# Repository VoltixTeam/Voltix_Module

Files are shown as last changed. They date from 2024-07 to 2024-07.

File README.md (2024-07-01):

# Voltix Module Hardware Design Files



The Voltix Module is a stamp-sized unit (27.2mm by 15.2mm) that can be soldered onto a user's \ac{pcb} with additional circuitry like sensors or harvesters to create deployment-ready battery-free devices quickly.
It integrates harvesting circuitry, two MCUs, an RTC, a PCB antenna, and an LED on a compact 4-layer PCB enclosed in a metal RF shield.
The module features breadboard-compatible castellated holes exposing essential signals, including 11 GPIO, two of which can also function as analog inputs.
Four additional signals on the back of the module are available when reflow-soldered onto a carrier board.

For more details and pinouts, refer to the [documentation](https://voltix-docs.vercel.app/hardware/module.html).

Latest design files:
 - [Schematics](https://voltix-docs.vercel.app/artifacts/module/latest/schematics.pdf)
 - [Layout](https://voltix-docs.vercel.app/artifacts/module/latest/pcb.pdf)
 - [3D rendering](https://voltix-docs.vercel.app/artifacts/module/latest/3drendering.png)
 - [3D step model](./resources/VoltixModule.step)
 - [Kicad schematic symbol](./resources/VoltixModule.kicad_sym)
 - [Kicad footprint](./resources/VoltixModule.pretty)

Rendering of Voltix module Voltix module

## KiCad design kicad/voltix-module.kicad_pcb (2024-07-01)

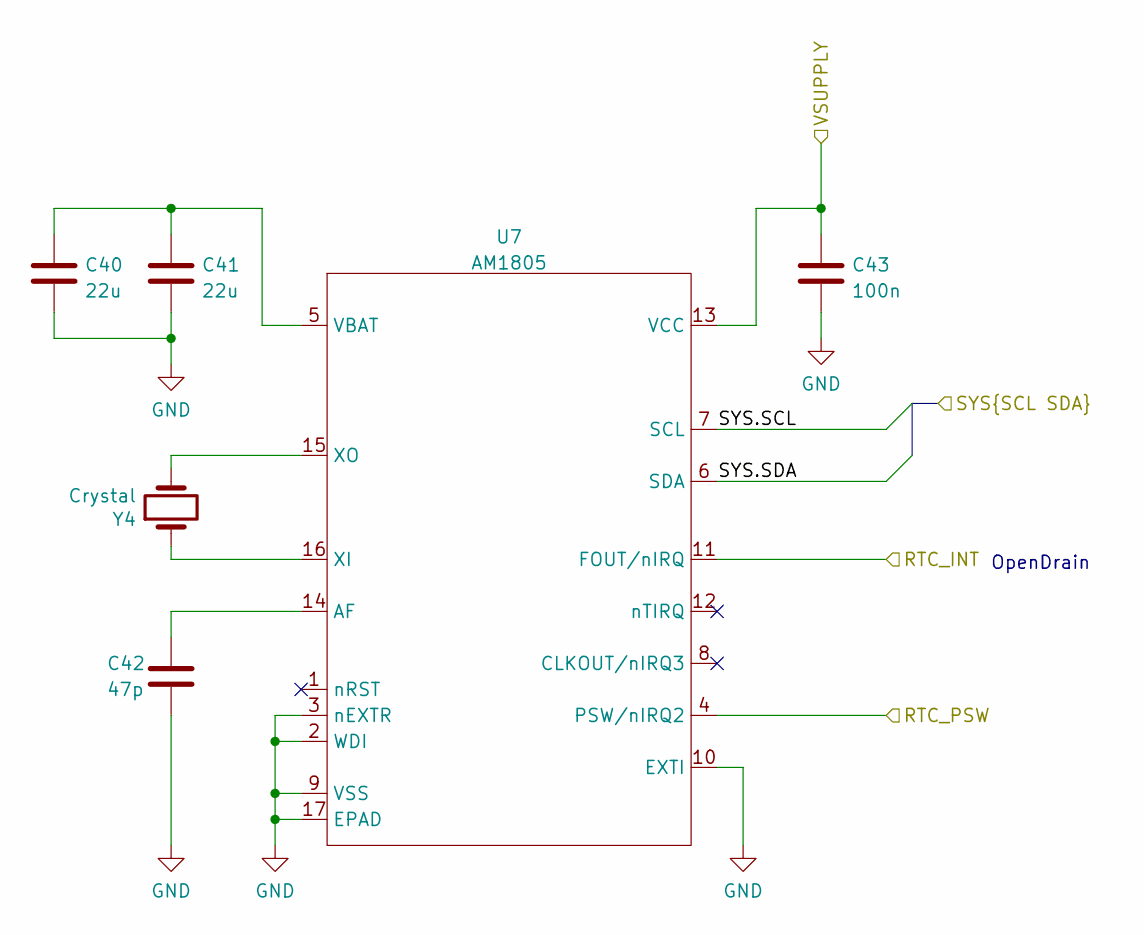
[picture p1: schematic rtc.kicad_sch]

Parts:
C40, C41: 22u; C_0402_1005Metric; MPN GRM158R61A226ME15D
C42: 47p; C_0201_0603Metric; MPN CC0201JRNPO9BN470
C43: 100n; C_0201_0603Metric; MPN GRM033R61A104ME15D
U7: AM1805; AM_QFN16; MPN AM1805
Y4: Crystal; ECX-12R; MPN CM8V-T1A-32.768KHZ-9PF-20PPM-TA-QC

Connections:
/Board Connectors/SYS.SCL: U7.7 (SCL); also elsewhere on the board
/Board Connectors/SYS.SDA: U7.6 (SDA); also elsewhere on the board
/Board Connectors/VSHUNT: C43.1, U7.13 (VCC); also elsewhere on the board
/MSP430FR/RTC_INT: U7.11 (FOUT/nIRQ); also elsewhere on the board
/Power Supply/RTC_PSW: U7.4 (PSW/nIRQ2); also elsewhere on the board
GND: C40.2, C41.2, C42.2, C43.2, U7.2 (WDI), U7.3 (nEXTR), U7.9 (VSS), U7.10 (EXTI), U7.17 (EPAD); also elsewhere on the board
unnamed: C42.1, U7.14 (AF)
unnamed: C40.1, C41.1, U7.5 (VBAT)
unnamed: U7.16 (XI), Y4.1
unnamed: U7.15 (XO), Y4.2

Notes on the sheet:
OpenDrain

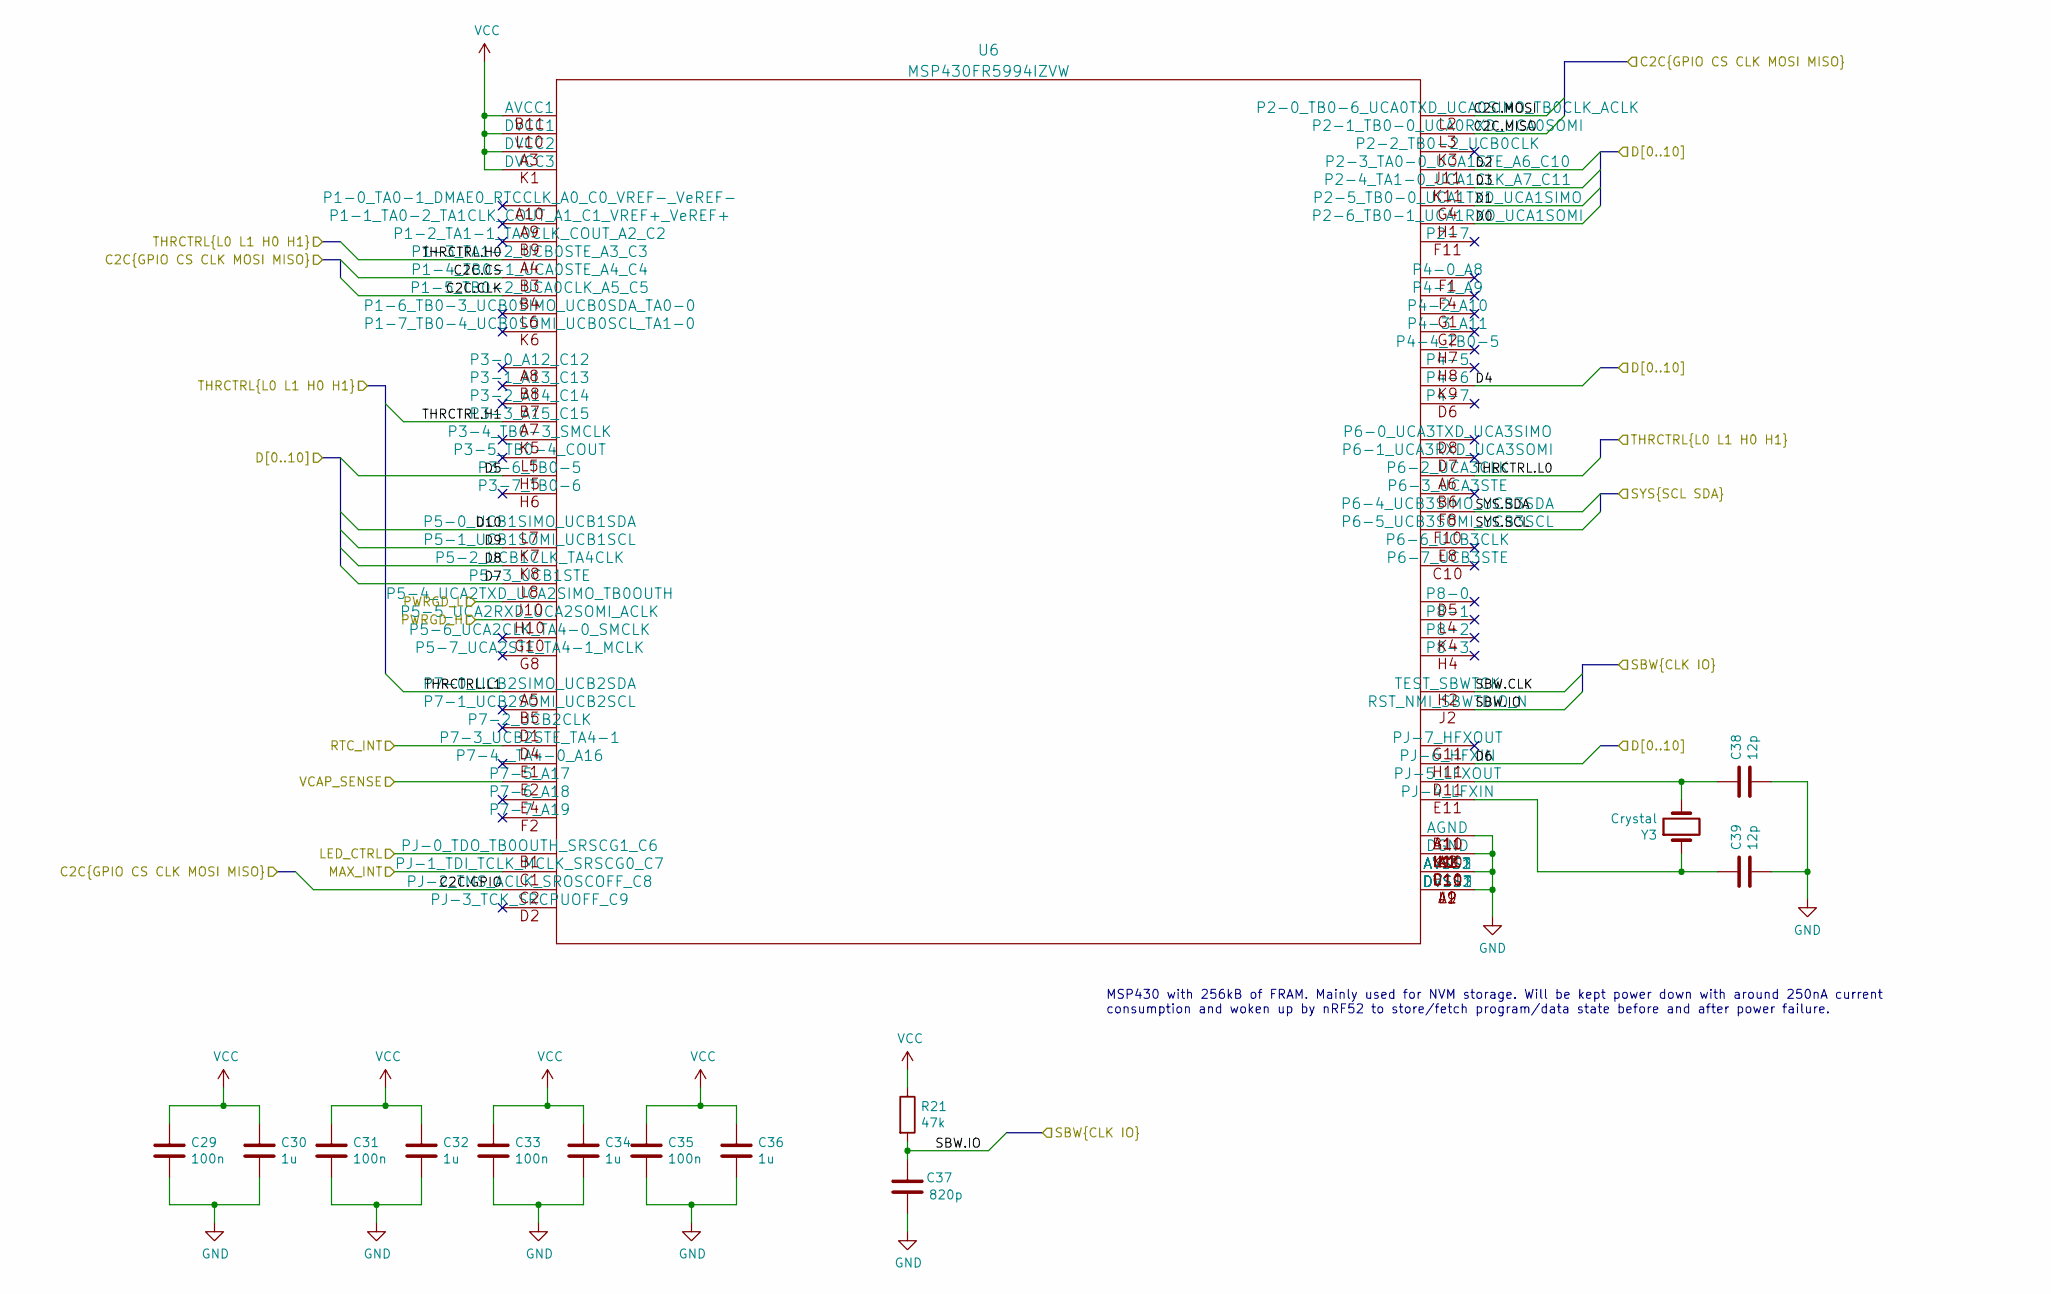
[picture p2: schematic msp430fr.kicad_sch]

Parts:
C29, C31, C33, C35: 100n; C_0201_0603Metric; MPN GRM033R61A104ME15D
C30, C32, C34, C36: 1u; C_0201_0603Metric; MPN GRM033R61C105ME15D
C37: 820p; C_0201_0603Metric; MPN GRM0335C1H821JE01D
C38, C39: 12p; C_0201_0603Metric; MPN GRM0335C1H120GA01D
R21: 47k; R_0201_0603Metric; MPN RC0201FR-0747KL
U6: MSP430FR5994IZVW; TI_ZVW; MPN MSP430FR5994IZVW
Y3: Crystal; ECX-12R; MPN CM8V-T1A-32.768KHZ-9PF-20PPM-TA-QC

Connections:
/Board Connectors/D0: U6.H1 (P2-6_TB0-1_UCA1RXD_UCA1SOMI); also elsewhere on the board
/Board Connectors/D1: U6.G4 (P2-5_TB0-0_UCA1TXD_UCA1SIMO); also elsewhere on the board
/Board Connectors/D2: U6.J11 (P2-3_TA0-0_UCA1STE_A6_C10); also elsewhere on the board
/Board Connectors/D3: U6.K11 (P2-4_TA1-0_UCA1CLK_A7_C11); also elsewhere on the board
/Board Connectors/D4: U6.K9 (P4-6); also elsewhere on the board
/Board Connectors/D5: U6.H5 (P3-6_TB0-5); also elsewhere on the board
/Board Connectors/D6: U6.H11 (PJ-6_HFXIN); also elsewhere on the board
/Board Connectors/D7: U6.L8 (P5-3_UCB1STE); also elsewhere on the board
/Board Connectors/D8: U6.K8 (P5-2_UCB1CLK_TA4CLK); also elsewhere on the board
/Board Connectors/D9: U6.K7 (P5-1_UCB1SOMI_UCB1SCL); also elsewhere on the board
/Board Connectors/D10: U6.L7 (P5-0_UCB1SIMO_UCB1SDA); also elsewhere on the board
/Board Connectors/LED_CTRL: U6.B1 (PJ-0_TDO_TB0OUTH_SRSCG1_C6); also elsewhere on the board
/Board Connectors/SBW.CLK: U6.H2 (TEST_SBWTCK); also elsewhere on the board
/Board Connectors/SBW.IO: C37.1, R21.2, U6.J2 (RST_NMI_SBWTDIO_N); also elsewhere on the board
/Board Connectors/SYS.SCL: U6.F10 (P6-5_UCB3SOMI_UCB3SCL); also elsewhere on the board
/Board Connectors/SYS.SDA: U6.F8 (P6-4_UCB3SIMO_UCB3SDA); also elsewhere on the board
/Board Connectors/VCAP_SENSE: U6.E2 (P7-5_A17); also elsewhere on the board
/Energy Management/PWRGD_H: U6.H10 (P5-5_UCA2RXD_UCA2SOMI_ACLK); also elsewhere on the board
/Energy Management/PWRGD_L: U6.J10 (P5-4_UCA2TXD_UCA2SIMO_TB0OUTH); also elsewhere on the board
/Energy Management/THRCTRL.H0: U6.A4 (P1-3_TA1-2_UCB0STE_A3_C3); also elsewhere on the board
/Energy Management/THRCTRL.H1: U6.A7 (P3-3_A15_C15); also elsewhere on the board
/Energy Management/THRCTRL.L0: U6.A6 (P6-2_UCA3CLK); also elsewhere on the board
/Energy Management/THRCTRL.L1: U6.A5 (P7-0_UCB2SIMO_UCB2SDA); also elsewhere on the board
/MSP430FR/C2C.CLK: U6.B4 (P1-5_TB0-2_UCA0CLK_A5_C5); also elsewhere on the board
/MSP430FR/C2C.CS: U6.B3 (P1-4_TB0-1_UCA0STE_A4_C4); also elsewhere on the board
/MSP430FR/C2C.GPIO: U6.C2 (PJ-2_TMS_ACLK_SROSCOFF_C8); also elsewhere on the board
/MSP430FR/C2C.MISO: U6.L3 (P2-1_TB0-0_UCA0RXD_UCA0SOMI); also elsewhere on the board
/MSP430FR/C2C.MOSI: U6.L2 (P2-0_TB0-6_UCA0TXD_UCA0SIMO_TB0CLK_ACLK); also elsewhere on the board
/MSP430FR/MAX_INT: U6.C1 (PJ-1_TDI_TCLK_MCLK_SRSCG0_C7); also elsewhere on the board
/MSP430FR/RTC_INT: U6.D4 (P7-3_UCB2STE_TA4-1); also elsewhere on the board
GND: C29.2, C30.2, C31.2, C32.2, C33.2, C34.2, C35.2, C36.2, C37.2, C38.2, C39.2, U6.A1 (DGND), U6.A2 (DVSS2), U6.A11 (AGND), U6.B10 (AGND), U6.C11 (AVSS1), U6.D10 (AVSS2), U6.E10 (AVSS3), U6.J1 (DVSS3), U6.K2 (DGND), U6.K10 (DGND), U6.L1 (DGND), U6.L9 (DVSS1), U6.L11 (DGND); also elsewhere on the board
unnamed: C39.1, U6.E11 (PJ-4_LFXIN), Y3.1
unnamed: C38.1, U6.D11 (PJ-5_LFXOUT), Y3.2
VCC: C29.1, C30.1, C31.1, C32.1, C33.1, C34.1, C35.1, C36.1, R21.1, U6.A3 (DVCC2), U6.B11 (AVCC1), U6.K1 (DVCC3), U6.L10 (DVCC1); also elsewhere on the board

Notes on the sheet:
MSP430 with 256kB of FRAM. Mainly used for NVM storage. Will be kept power down with around 250nA current consumption and woken up by nRF52 to store/fetch program/data state before and after power failure.

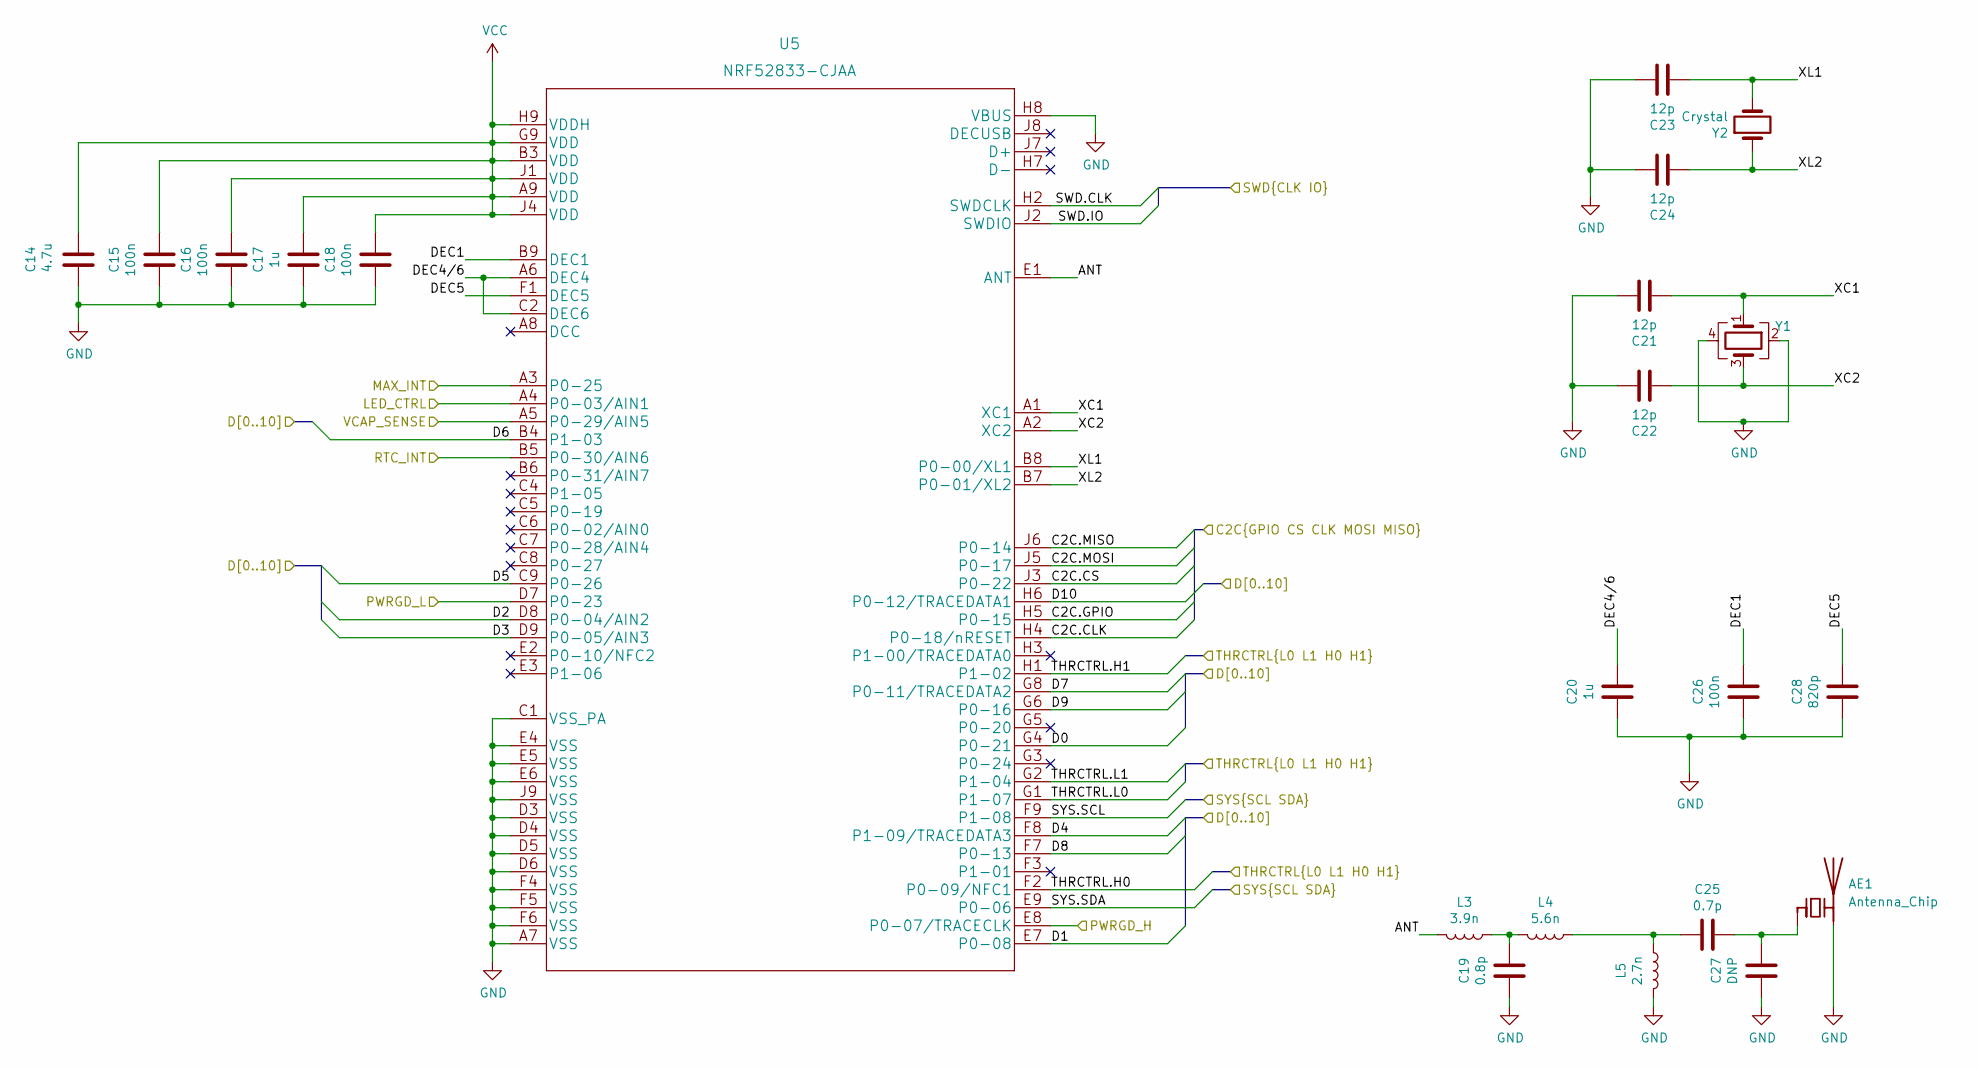
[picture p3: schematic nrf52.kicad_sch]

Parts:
AE1: Antenna_Chip; Texas_SWRA117D_2.4GHz_Left
C14: 4.7u; C_0402_1005Metric; MPN CL05A475MP5NRNC
C15, C16, C18, C26: 100n; C_0201_0603Metric; MPN GRM033R61A104ME15D
C17, C20: 1u; C_0201_0603Metric; MPN GRM033R61C105ME15D
C19: 0.8p; RFSMD_0201_0603Metric; MPN GRT0335C1HR80WA02D
C21, C22, C23, C24: 12p; C_0201_0603Metric; MPN GRM0335C1H120GA01D
C25: 0.7p; RFSMD_0201_0603Metric; MPN GRM0335C1HR70WA01D
C27: DNP; RFSMD_0201_0603Metric
C28: 820p; C_0201_0603Metric; MPN GRM0335C1H821JE01D
L3: 3.9n; RFSMD_0201_0603Metric; MPN LQP03TN3N9B02D
L4: 5.6n; RFSMD_0201_0603Metric; MPN LQP03TN5N6J02D
L5: 2.7n; RFSMD_0201_0603Metric; MPN LQP03TN2N7B02D
U5: NRF52833-CJAA; MPN NRF52833-CJAA
Y1: ECS-320-8-47B-7KM-TR; ECS_ECX-1247B; MPN ECS-320-CDX-2152
Y2: Crystal; ECX-12R; MPN CM8V-T1A-32.768KHZ-9PF-20PPM-TA-QC

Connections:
/Board Connectors/D0: U5.G4 (P0-21); also elsewhere on the board
/Board Connectors/D1: U5.E7 (P0-08); also elsewhere on the board
/Board Connectors/D2: U5.D8 (P0-04/AIN2); also elsewhere on the board
/Board Connectors/D3: U5.D9 (P0-05/AIN3); also elsewhere on the board
/Board Connectors/D4: U5.F8 (P1-09/TRACEDATA3); also elsewhere on the board
/Board Connectors/D5: U5.C9 (P0-26); also elsewhere on the board
/Board Connectors/D6: U5.B4 (P1-03); also elsewhere on the board
/Board Connectors/D7: U5.G8 (P0-11/TRACEDATA2); also elsewhere on the board
/Board Connectors/D8: U5.F7 (P0-13); also elsewhere on the board
/Board Connectors/D9: U5.G6 (P0-16); also elsewhere on the board
/Board Connectors/D10: U5.H6 (P0-12/TRACEDATA1); also elsewhere on the board
/Board Connectors/LED_CTRL: U5.A4 (P0-03/AIN1); also elsewhere on the board
/Board Connectors/SWD.CLK: U5.H2 (SWDCLK); also elsewhere on the board
/Board Connectors/SWD.IO: U5.J2 (SWDIO); also elsewhere on the board
/Board Connectors/SYS.SCL: U5.F9 (P1-08); also elsewhere on the board
/Board Connectors/SYS.SDA: U5.E9 (P0-06); also elsewhere on the board
/Board Connectors/VCAP_SENSE: U5.A5 (P0-29/AIN5); also elsewhere on the board
/Energy Management/PWRGD_H: U5.E8 (P0-07/TRACECLK); also elsewhere on the board
/Energy Management/PWRGD_L: U5.D7 (P0-23); also elsewhere on the board
/Energy Management/THRCTRL.H0: U5.F2 (P0-09/NFC1); also elsewhere on the board
/Energy Management/THRCTRL.H1: U5.H1 (P1-02); also elsewhere on the board
/Energy Management/THRCTRL.L0: U5.G1 (P1-07); also elsewhere on the board
/Energy Management/THRCTRL.L1: U5.G2 (P1-04); also elsewhere on the board
/MSP430FR/C2C.CLK: U5.H4 (P0-18/nRESET); also elsewhere on the board
/MSP430FR/C2C.CS: U5.J3 (P0-22); also elsewhere on the board
/MSP430FR/C2C.GPIO: U5.H5 (P0-15); also elsewhere on the board
/MSP430FR/C2C.MISO: U5.J6 (P0-14); also elsewhere on the board
/MSP430FR/C2C.MOSI: U5.J5 (P0-17); also elsewhere on the board
/MSP430FR/MAX_INT: U5.A3 (P0-25); also elsewhere on the board
/MSP430FR/RTC_INT: U5.B5 (P0-30/AIN6); also elsewhere on the board
/nRF52/ANT: L3.2, U5.E1 (ANT)
/nRF52/DEC1: C26.2, U5.B9 (DEC1)
/nRF52/DEC4/6: C20.2, U5.A6 (DEC4), U5.C2 (DEC6)
/nRF52/DEC5: C28.2, U5.F1 (DEC5)
/nRF52/XC1: C21.1, U5.A1 (XC1), Y1.1
/nRF52/XC2: C22.1, U5.A2 (XC2), Y1.3
/nRF52/XL1: C23.1, U5.B8 (P0-00/XL1), Y2.2
/nRF52/XL2: C24.1, U5.B7 (P0-01/XL2), Y2.1
GND: AE1.2 (PCB_Trace), C14.2, C15.1, C16.1, C17.1, C18.1, C19.1, C20.1, C21.2, C22.2, C23.2, C24.2, C26.1, C27.1, C28.1, L5.2, U5.A7 (VSS), U5.C1 (VSS_PA), U5.D3 (VSS), U5.D4 (VSS), U5.D5 (VSS), U5.D6 (VSS), U5.E4 (VSS), U5.E5 (VSS), U5.E6 (VSS), U5.F4 (VSS), U5.F5 (VSS), U5.F6 (VSS), U5.H8 (VBUS), U5.J9 (VSS), Y1.2, Y1.4; also elsewhere on the board
unnamed: AE1.1 (FEED), C25.2, C27.2
unnamed: C19.2, L3.1, L4.2
unnamed: C25.1, L4.1, L5.1
VCC: C14.1, C15.2, C16.2, C17.2, C18.2, U5.A9 (VDD), U5.B3 (VDD), U5.G9 (VDD), U5.H9 (VDDH), U5.J1 (VDD), U5.J4 (VDD); also elsewhere on the board

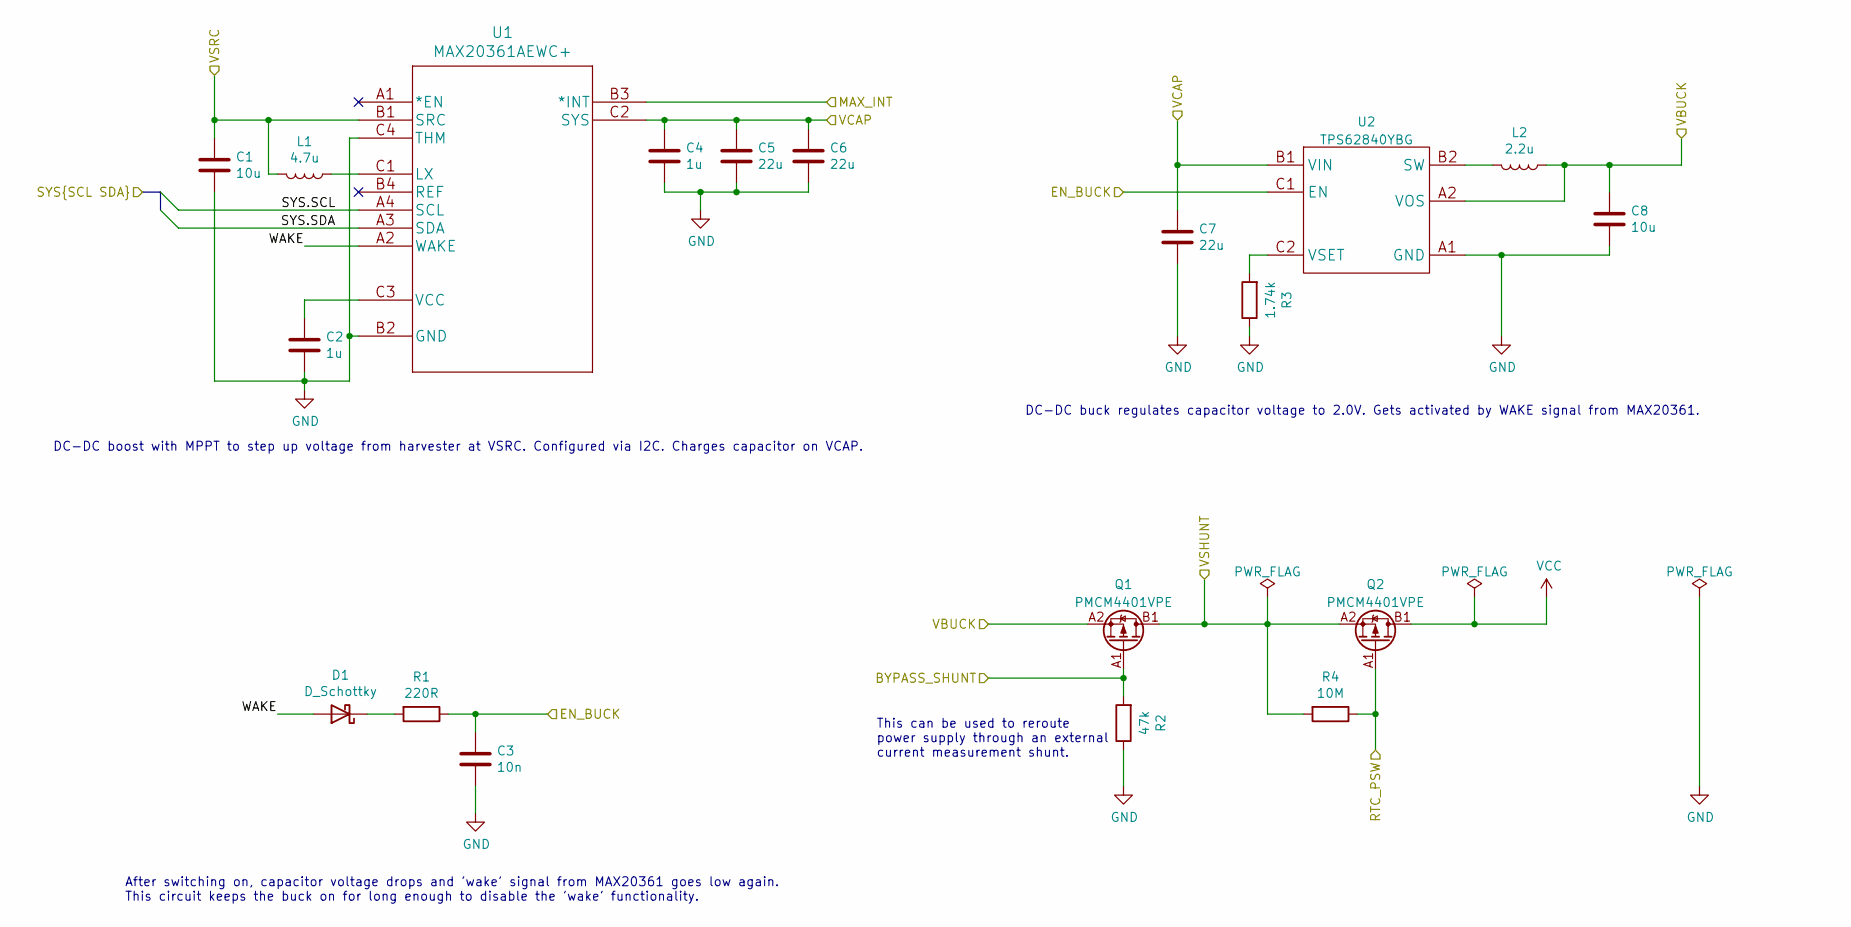
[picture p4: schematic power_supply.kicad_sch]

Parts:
C1, C8: 10u; C_0402_1005Metric; MPN GRM155R61A106ME11D
C2, C4: 1u; C_0201_0603Metric; MPN GRM033R61C105ME15D
C3: 10n; C_0201_0603Metric; MPN GRM033R61A103KA01D
C5, C6, C7: 22u; C_0402_1005Metric; MPN GRM158R61A226ME15D
D1: D_Schottky; D_0402_1005Metric; MPN CDBQR0130R
L1: 4.7u; L_0805_2012Metric; MPN MLZ2012N4R7LTD25
L2: 2.2u; L_0603_1608Metric; MPN MLZ1608N2R2LT000
Q1, Q2: PMCM4401VPE; NXP_WLCSP4; MPN PMCM4401VPEZ
R1: 220R; R_0201_0603Metric; MPN RC0201FR-07220RL
R2: 47k; R_0201_0603Metric; MPN RC0201FR-0747KL
R3: 1.74k; R_0201_0603Metric; MPN RC0201FR-071K74L
R4: 10M; R_0201_0603Metric; MPN RC0201FR-0710ML
U1: MAX20361AEWC+; MX_W121C1+2; MPN MAX20361AEWC+
U2: TPS62840YBG; TI_YBG6; MPN TPS62840YBG

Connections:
/Board Connectors/BYPASS_SHUNT: Q1.A1 (G), R2.2; also elsewhere on the board
/Board Connectors/EN_BUCK: C3.1, R1.1, U2.C1 (EN); also elsewhere on the board
/Board Connectors/SYS.SCL: U1.A4 (SCL); also elsewhere on the board
/Board Connectors/SYS.SDA: U1.A3 (SDA); also elsewhere on the board
/Board Connectors/VBUCK: C8.1, L2.1, Q1.A2 (S), U2.A2 (VOS); also elsewhere on the board
/Board Connectors/VCAP: C4.1, C5.1, C6.1, C7.1, U1.C2 (SYS), U2.B1 (VIN); also elsewhere on the board
/Board Connectors/VSHUNT: Q1.B1 (D), Q2.A2 (S), R4.2; also elsewhere on the board
/Board Connectors/VSRC: C1.1, L1.2, U1.B1 (SRC); also elsewhere on the board
/MSP430FR/MAX_INT: U1.B3 (*INT); also elsewhere on the board
/Power Supply/RTC_PSW: Q2.A1 (G), R4.1; also elsewhere on the board
/Power Supply/WAKE: D1.2 (A), U1.A2 (WAKE)
GND: C1.2, C2.2, C3.2, C4.2, C5.2, C6.2, C7.2, C8.2, R2.1, R3.1, U1.B2 (GND), U1.C4 (THM), U2.A1 (GND); also elsewhere on the board
unnamed: D1.1 (K), R1.2
unnamed: L1.1, U1.C1 (LX)
unnamed: C2.1, U1.C3 (VCC)
unnamed: L2.2, U2.B2 (SW)
unnamed: R3.2, U2.C2 (VSET)
VCC: Q2.B1 (D); also elsewhere on the board

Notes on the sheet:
After switching on, capacitor voltage drops and 'wake' signal from MAX20361 goes low again. This circuit keeps the buck on for long enough to disable the 'wake' functionality.
This can be used to reroute power supply through an external current measurement shunt.
DC-DC boost with MPPT to step up voltage from harvester at VSRC. Configured via I2C. Charges capacitor on VCAP.
DC-DC buck regulates capacitor voltage to 2.0V. Gets activated by WAKE signal from MAX20361.

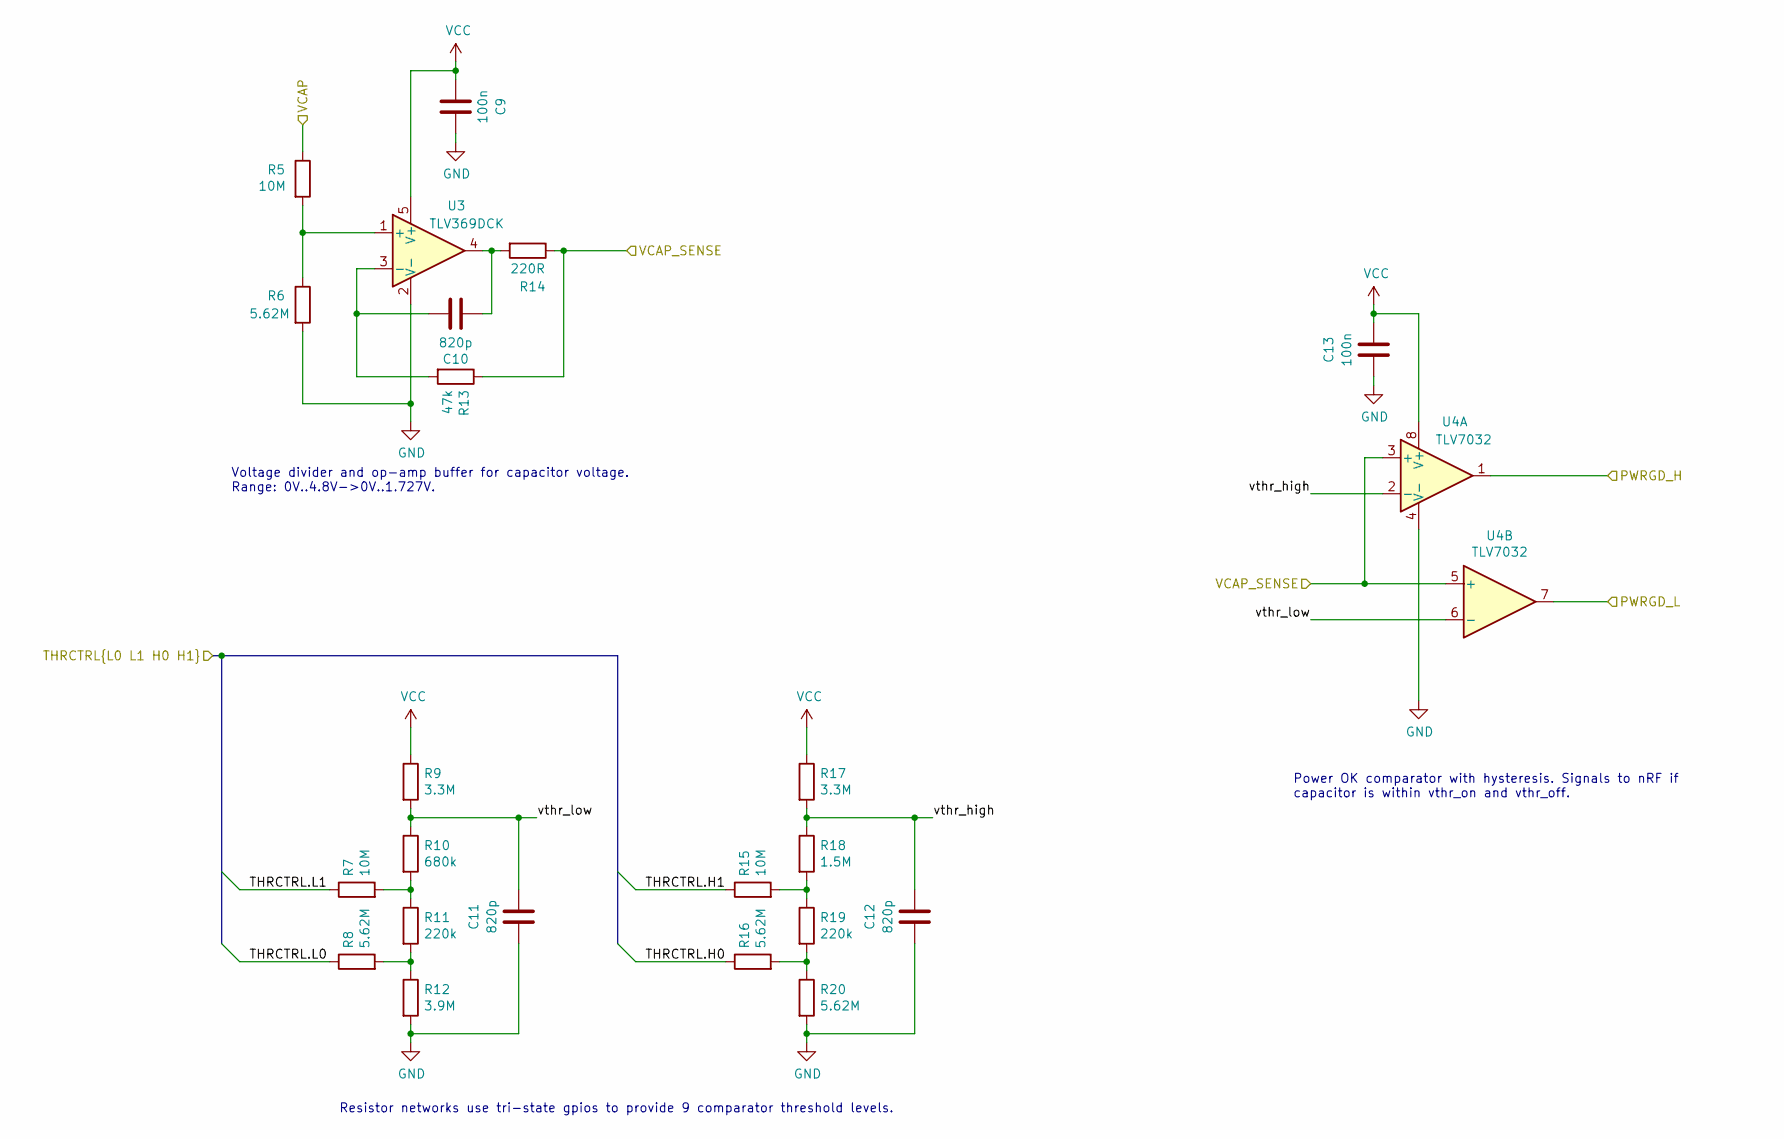
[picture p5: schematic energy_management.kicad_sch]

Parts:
C9, C13: 100n; C_0201_0603Metric; MPN GRM033R61A104ME15D
C10, C11, C12: 820p; C_0201_0603Metric; MPN GRM0335C1H821JE01D
R5, R7, R15: 10M; R_0201_0603Metric; MPN RC0201FR-0710ML
R6, R8, R16, R20: 5.62M; R_0201_0603Metric; MPN RC0201FR-075M62L
R9, R17: 3.3M; R_0201_0603Metric; MPN RC0201FR-073M3L
R10: 680k; R_0201_0603Metric; MPN RC0201FR-07680KL
R11, R19: 220k; R_0201_0603Metric; MPN RC0201FR-07220KL
R12: 3.9M; R_0201_0603Metric; MPN RC0201FR-073M9L
R13: 47k; R_0201_0603Metric; MPN RC0201FR-0747KL
R14: 220R; R_0201_0603Metric; MPN RC0201FR-07220RL
R18: 1.5M; R_0201_0603Metric; MPN RC0201FR-071M5L
U3: TLV369DCK; TI_SC70-5_DCK5; MPN TLV369IDCK
U4: TLV7032; TI_WSON8_DSG; MPN TLV7032DSG

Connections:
/Board Connectors/VCAP: R5.1; also elsewhere on the board
/Board Connectors/VCAP_SENSE: R13.1, R14.1, U4.3 (+), U4.5 (+); also elsewhere on the board
/Energy Management/PWRGD_H: U4.1; also elsewhere on the board
/Energy Management/PWRGD_L: U4.7; also elsewhere on the board
/Energy Management/THRCTRL.H0: R16.1; also elsewhere on the board
/Energy Management/THRCTRL.H1: R15.1; also elsewhere on the board
/Energy Management/THRCTRL.L0: R8.1; also elsewhere on the board
/Energy Management/THRCTRL.L1: R7.1; also elsewhere on the board
/Energy Management/vthr_high: C12.2, R17.2, R18.1, U4.2 (-)
/Energy Management/vthr_low: C11.2, R9.2, R10.1, U4.6 (-)
GND: C9.1, C11.1, C12.1, C13.1, R6.2, R12.2, R20.2, U3.2 (V-), U4.4 (V-), U4.9 (THM); also elsewhere on the board
unnamed: C10.1, R14.2, U3.4
unnamed: R7.2, R10.2, R11.1
unnamed: R8.2, R11.2, R12.1
unnamed: R15.2, R18.2, R19.1
unnamed: R16.2, R19.2, R20.1
unnamed: R5.2, R6.1, U3.1 (+)
unnamed: C10.2, R13.2, U3.3 (-)
VCC: C9.2, C13.2, R9.1, R17.1, U3.5 (V+), U4.8 (V+); also elsewhere on the board

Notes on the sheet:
Power OK comparator with hysteresis. Signals to nRF if capacitor is within vthr_on and vthr_off.
Resistor networks use tri-state gpios to provide 9 comparator threshold levels.
Voltage divider and op-amp buffer for capacitor voltage. Range: 0V..4.8V->0V..1.727V.

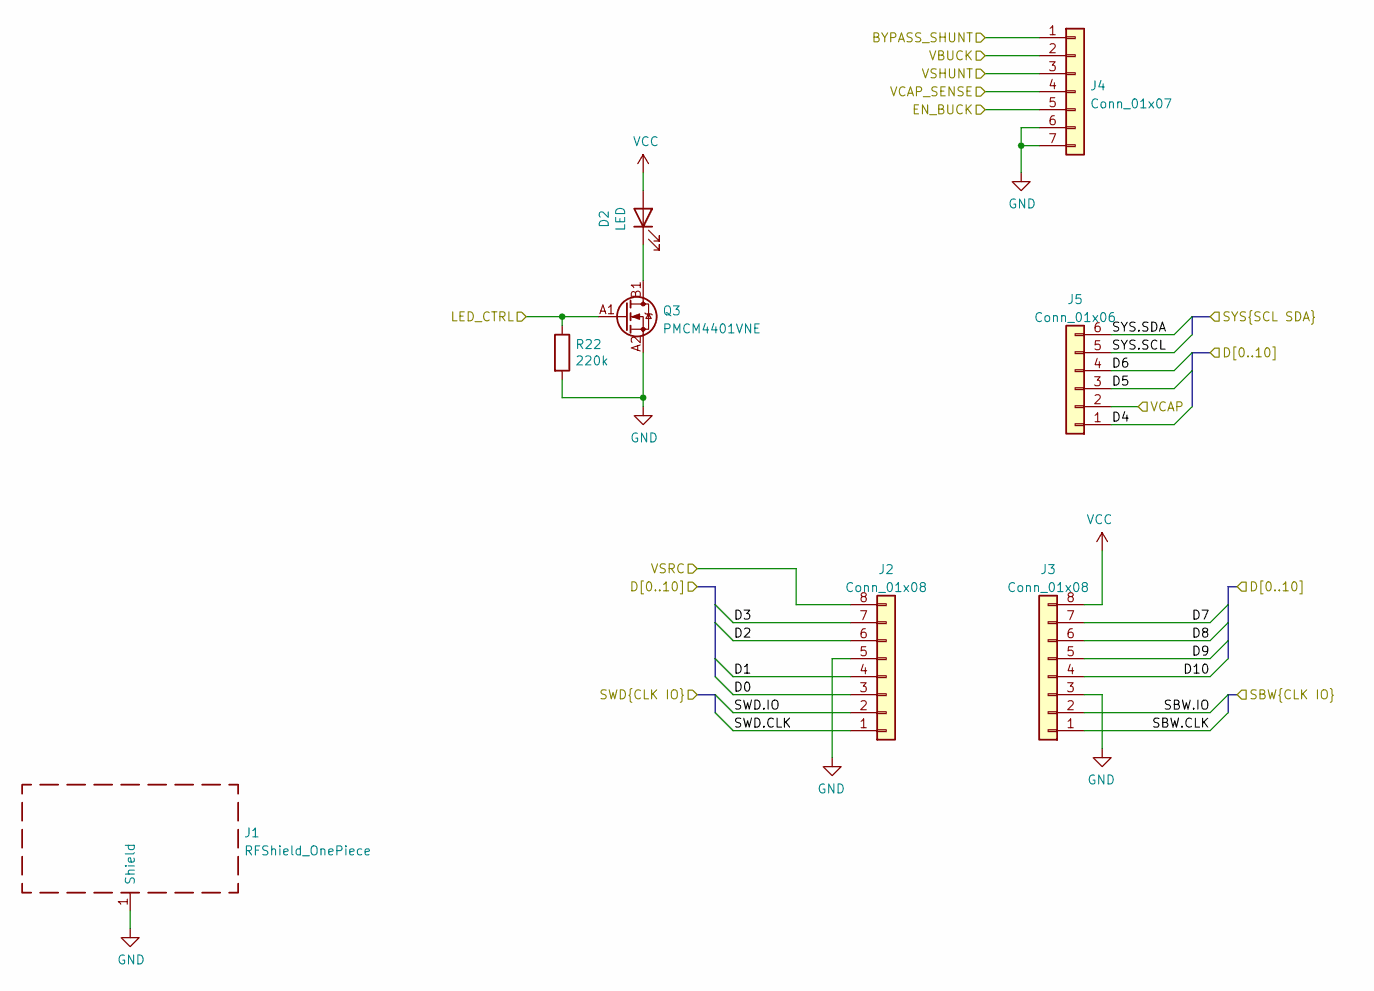
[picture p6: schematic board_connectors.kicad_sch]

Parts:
D2: LED; LED_0402_1005Metric; MPN 5988A20107F
J1: RFShield_OnePiece; EMI_SHIELD_CSTM
J2: Conn_01x08; CastellatedHoles_1x08_P2.54mm_Left
J3: Conn_01x08; CastellatedHoles_1x08_P2.54mm_Right
J4: Conn_01x07; BackPads
J5: Conn_01x06; CastellatedHoles_1x06_P2.54mm
Q3: PMCM4401VNE; NXP_WLCSP4; MPN PMCM4401VNEAZ
R22: 220k; R_0201_0603Metric; MPN RC0201FR-07220KL

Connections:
/Board Connectors/BYPASS_SHUNT: J4.1; also elsewhere on the board
/Board Connectors/D0: J2.3; also elsewhere on the board
/Board Connectors/D1: J2.4; also elsewhere on the board
/Board Connectors/D2: J2.6; also elsewhere on the board
/Board Connectors/D3: J2.7; also elsewhere on the board
/Board Connectors/D4: J5.1; also elsewhere on the board
/Board Connectors/D5: J5.3; also elsewhere on the board
/Board Connectors/D6: J5.4; also elsewhere on the board
/Board Connectors/D7: J3.7; also elsewhere on the board
/Board Connectors/D8: J3.6; also elsewhere on the board
/Board Connectors/D9: J3.5; also elsewhere on the board
/Board Connectors/D10: J3.4; also elsewhere on the board
/Board Connectors/EN_BUCK: J4.5; also elsewhere on the board
/Board Connectors/LED_CTRL: Q3.A1 (G), R22.1; also elsewhere on the board
/Board Connectors/SBW.CLK: J3.1; also elsewhere on the board
/Board Connectors/SBW.IO: J3.2; also elsewhere on the board
/Board Connectors/SWD.CLK: J2.1; also elsewhere on the board
/Board Connectors/SWD.IO: J2.2; also elsewhere on the board
/Board Connectors/SYS.SCL: J5.5; also elsewhere on the board
/Board Connectors/SYS.SDA: J5.6; also elsewhere on the board
/Board Connectors/VBUCK: J4.2; also elsewhere on the board
/Board Connectors/VCAP: J5.2; also elsewhere on the board
/Board Connectors/VCAP_SENSE: J4.4; also elsewhere on the board
/Board Connectors/VSHUNT: J4.3; also elsewhere on the board
/Board Connectors/VSRC: J2.8; also elsewhere on the board
GND: J1.1 (Shield), J2.5, J3.3, J4.6, J4.7, Q3.A2 (S), R22.2; also elsewhere on the board
unnamed: D2.1 (K), Q3.B1 (D)
VCC: D2.2 (A), J3.8; also elsewhere on the board

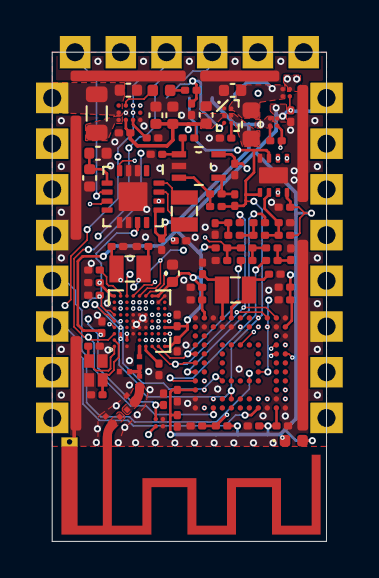
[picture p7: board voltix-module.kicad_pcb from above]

Board: 4 copper layers, 15.2 x 27.2 mm, 92 parts (1 on the bottom side), 74 nets.

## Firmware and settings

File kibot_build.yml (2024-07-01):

kibot:
  version: 1

preflight:
  check_zone_fills: true
  erc:
    filters:
    - filter: 'ignore simulation errors'
      error: 'simulation_model_issue'
  drc:
    filters:
    - filter: 'ignore pcb antenna issues'
      error: 'clearance'
      regex: '\(66\.752 mm, 98\.509672 mm\): Track \[Net-\(AE1-FEED\)\] on F\.Cu'
    - filter: 'ignore pcb antenna issues'
      error: 'clearance'
      regex: '\(67\.752 mm, 98\.5097 mm\): Track \(arc\) \[Net-\(AE1-FEED\)\] on F\.Cu'
    - filter: 'ignore pcb antenna issues'
      error: 'clearance'
      regex: '\(64\.912 mm, 98\.662 mm\): Track \[GND\] on F\.Cu'
    - filter: 'ignore pcb antenna issues'
      error: 'clearance'
      regex: '\(66\.752 mm, 98\.792 mm\): Pad 1 \[Net-\(AE1-FEED\)\] of AE1 on F\.Cu'
    - filter: 'ignore pcb antenna issues'
      error: 'clearance'
      regex: '\(64\.652 mm, 98\.792 mm\): PTH pad 2 \[GND\] of AE1'
outputs:
  # PDF Schematic Print (Portable Document Format):
  # This is the main format to document your schematic.
  # This output is what you get from the 'File/Print' menu in eeschema.
  - name: 'pdf_sch_print'
    comment: 'Exports schematics to PDF'
    type: 'pdf_sch_print'
    dir: '.'
    options:
      # [string='%f-%i%I%v.%x'] Filename for the output PDF (%i=schematic, %x=pdf). Affected by global options
      output: 'schematics.%x'

  - name: 'pcb_print'
    comment: 'Prints the PCB'
    type: 'pcb_print'
    dir: '.'
    options:
      # [number=0] Default horizontal margin used for the autoscaling mode [mm]
      autoscale_margin_x: 25
      # [number=0] Default vertical margin used for the autoscaling mode [mm]
      autoscale_margin_y: 25
      # [boolean=false] Add the `Edge.Cuts` to all the pages
      force_edge_cuts: true
      # [string='PDF'] [PDF,SVG,PNG,EPS,PS] Format for the output file/s.
      # Note that for PS you need `ghostscript` which isn't part of the default docker images
      format: 'PDF'
      # [string='%f-%i%I%v.%x'] Filename for the output (%i=assembly, %x=pdf/ps)/(%i=assembly_page_NN, %x=svg/png/eps).
      # Consult the `page_number_as_extension` and `page_id` options. Affected by global options
      output: 'pcb.%x'
      # [list(dict)] List of pages to include in the output document.
      # Each page contains one or more layers of the PCB
      pages:
        # [number=1.0] Scale factor (0 means autoscaling)
        - scaling: 5.0
          # [list(dict)|list(string)|string] List of layers printed in this page.
          # Order is important, the last goes on top.
          # You can reuse other layers lists, some options aren't used here, but they are valid
          layers:
            - 'F.Cu'
          # [string='Assembly'] Text to use for the `sheet` in the title block
          sheet: 'Top Copper'
        # [number=1.0] Scale factor (0 means autoscaling)
        - scaling: 4.3
          # [list(dict)|list(string)|string] List of layers printed in this page.
          # Order is important, the last goes on top.
          # You can reuse other layers lists, some options aren't used here, but they are valid
          layers:
            - 'B.Cu'
          # [string='Assembly'] Text to use for the `sheet` in the title block
          sheet: 'Bottom Copper'
        # [number=1.0] Scale factor (0 means autoscaling)
        - scaling: 4.3
          # [list(dict)|list(string)|string] List of layers printed in this page.
          # Order is important, the last goes on top.
          # You can reuse other layers lists, some options aren't used here, but they are valid
          layers:
            - 'sig1.Cu'
          # [string='Assembly'] Text to use for the `sheet` in the title block
          sheet: 'Inner1 Copper'
        # [number=1.0] Scale factor (0 means autoscaling)
        - scaling: 4.3
          # [list(dict)|list(string)|string] List of layers printed in this page.
          # Order is important, the last goes on top.
          # You can reuse other layers lists, some options aren't used here, but they are valid
          layers:
            - 'gnd.Cu'
          # [string='Assembly'] Text to use for the `sheet` in the title block
          sheet: 'Inner2 Copper'
        # [number=1.0] Scale factor (0 means autoscaling)
        - scaling: 4.3
          # [list(dict)|list(string)|string] List of layers printed in this page.
          # Order is important, the last goes on top.
          # You can reuse other layers lists, some options aren't used here, but they are valid
          layers:
            - 'F.Mask'
          # [string='Assembly'] Text to use for the `sheet` in the title block
          sheet: 'Top Solder Mask'
          # [number=1.0] Scale factor (0 means autoscaling)
        - scaling: 4.3
          # [list(dict)|list(string)|string] List of layers printed in this page.
          # Order is important, the last goes on top.
          # You can reuse other layers lists, some options aren't used here, but they are valid
          layers:
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
